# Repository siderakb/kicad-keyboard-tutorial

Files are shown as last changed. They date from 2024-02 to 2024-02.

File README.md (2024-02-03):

# KiCad Keyboard Tutorial

KiCAD 教學示範用的 60% 機械鍵盤。

[線上預覽](https://kicanvas.org/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)，由 [KiCanvas](https://github.com/theacodes/kicanvas) 提供。

- YouTube: [自製QMK鍵盤-KiCAD鍵盤PCB繪製教學  (上)](https://youtu.be/DOluUYmqIs4)
- Blog: [[自製QMK鍵盤-4] KiCAD鍵盤PCB繪製教學  (上)](https://ziteh.github.io/posts/diyqmkkeyboard-pcb-layout-sch/)

## 用法

從 Code 按鈕或 [Releases](https://github.com/siderakb/kicad-keyboard-tutorial/releases) 頁面下載專案，或使用 Git 指令：
```
git clone --recurse-submodules https://github.com/siderakb/kicad-keyboard-tutorial.git
```

需要另外安裝 Footprint 庫：[ebastler/marbastlib](https://github.com/ebastler/marbastlib)。

本專案使用的 KiCad 版本爲 `Ver 7.0.8`。

## 授權許可

- [`my-keyboard`](./my-keyboard/) 資料夾：根據 [CERN-OHL-P v2](./LICENSE) 授權。
- [`key-switches.pretty`](https://github.com/siderakb/key-switches.pretty) 資料夾：根據該庫自身的授權許可進行授權。

請注意，根據授權許可，不提供任何形式的保固或保證。

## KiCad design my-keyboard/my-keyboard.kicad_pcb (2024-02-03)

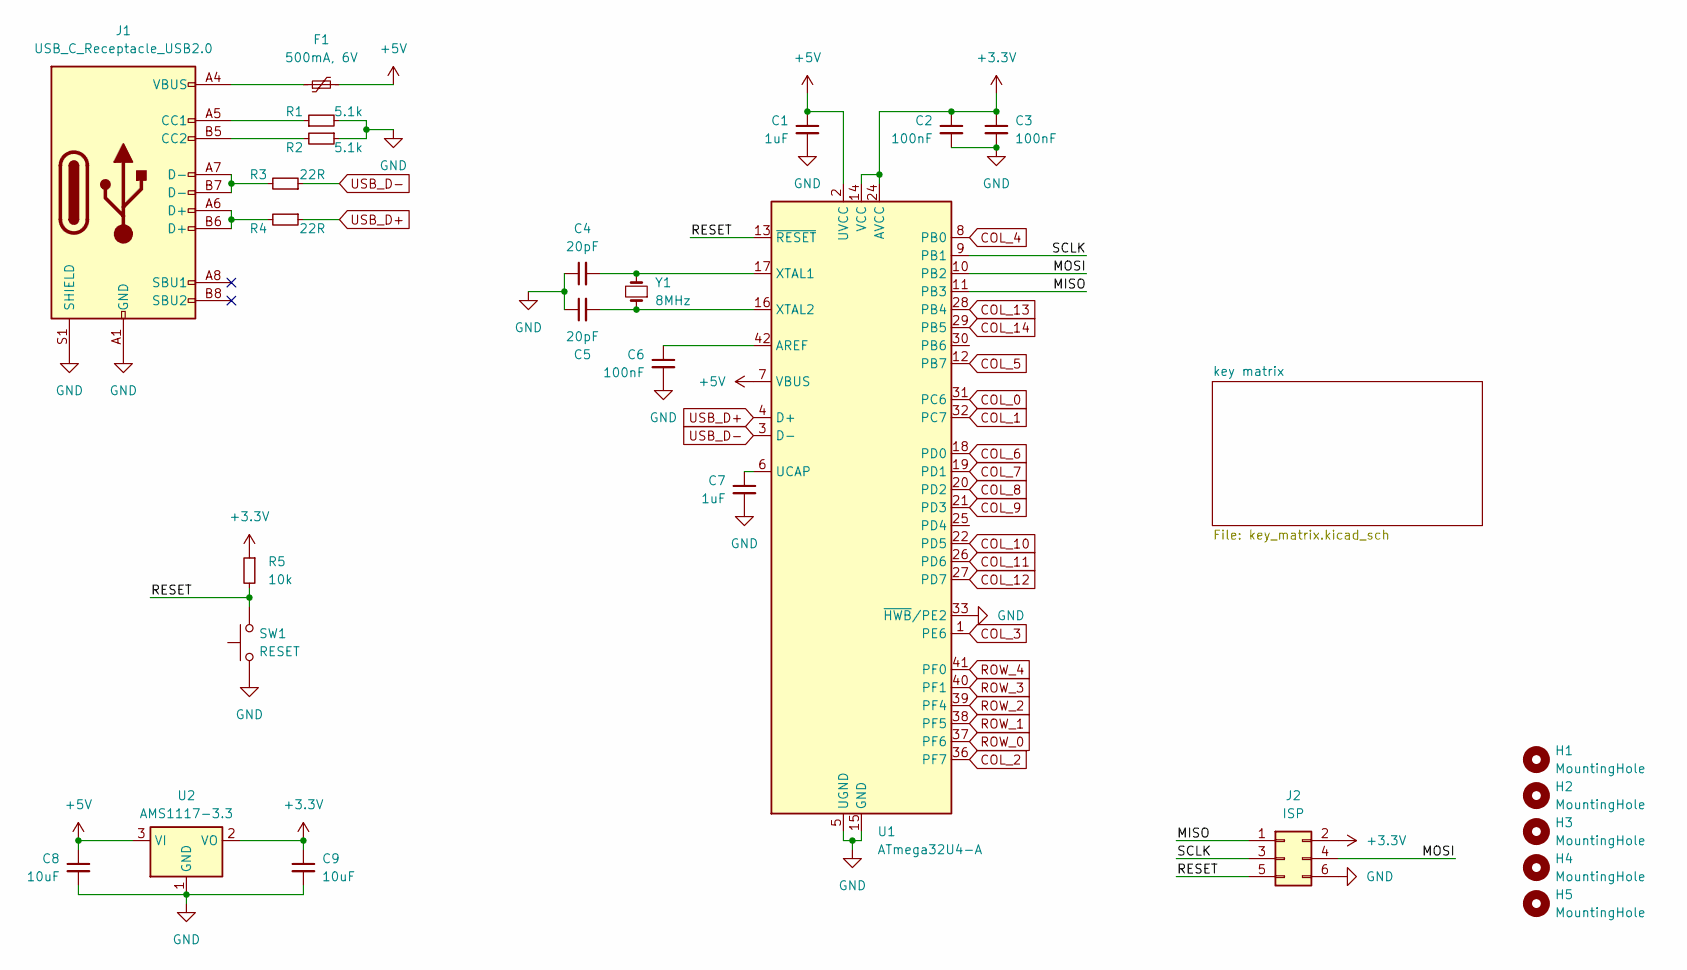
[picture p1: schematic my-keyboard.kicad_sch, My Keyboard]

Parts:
C1, C7: 1uF; C_0603_1608Metric
C2, C3, C6: 100nF; C_0603_1608Metric
C4, C5: 20pF; C_0603_1608Metric
C8, C9: 10uF; C_0603_1608Metric
F1: 500mA, 6V; Fuse_0805_2012Metric
H1, H2, H3, H4, H5: MountingHole; MountingHole_3.2mm_M3
J1: USB_C_Receptacle_USB2.0; USB_C_Receptacle_HRO_TYPE-C-31-M-12
J2: ISP; PinHeader_2x03_P2.54mm_Vertical
R1, R2: 5.1k; R_0603_1608Metric
R3, R4: 22R; R_0603_1608Metric
R5: 10k; R_0603_1608Metric
SW1: RESET; SW_SPST_CK_RS282G05A3
U1: ATmega32U4-A; TQFP-44_10x10mm_P0.8mm
U2: AMS1117-3.3; SOT-223-3_TabPin2
Y1: 8MHz; Crystal_SMD_3215-2Pin_3.2x1.5mm

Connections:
+3.3V: C2.1, C3.1, C9.1, J2.2, R5.1, U1.14 (VCC), U1.24 (AVCC), U1.34 (VCC), U1.44 (AVCC), U2.2 (VO)
+5V: C1.1, C8.1, F1.2, U1.2 (UVCC), U1.7 (VBUS), U2.3 (VI)
/MISO: J2.1, U1.11 (PB3)
/MOSI: J2.4, U1.10 (PB2)
/RESET: J2.5, R5.2, SW1.2, U1.13 (~RESET)
/SCLK: J2.3, U1.9 (PB1)
COL_0: U1.31 (PC6); also elsewhere on the board
COL_1: U1.32 (PC7); also elsewhere on the board
COL_2: U1.36 (PF7); also elsewhere on the board
COL_3: U1.1 (PE6); also elsewhere on the board
COL_4: U1.8 (PB0); also elsewhere on the board
COL_5: U1.12 (PB7); also elsewhere on the board
COL_6: U1.18 (PD0); also elsewhere on the board
COL_7: U1.19 (PD1); also elsewhere on the board
COL_8: U1.20 (PD2); also elsewhere on the board
COL_9: U1.21 (PD3); also elsewhere on the board
COL_10: U1.22 (PD5); also elsewhere on the board
COL_11: U1.26 (PD6); also elsewhere on the board
COL_12: U1.27 (PD7); also elsewhere on the board
COL_13: U1.28 (PB4); also elsewhere on the board
COL_14: U1.29 (PB5); also elsewhere on the board
GND: C1.2, C2.2, C3.2, C4.1, C5.1, C6.2, C7.2, C8.2, C9.2, J1.A1 (GND), J1.A12 (GND), J1.B1 (GND), J1.B12 (GND), J1.S1 (SHIELD), J2.6, R1.2, R2.1, SW1.1, U1.5 (UGND), U1.15 (GND), U1.23 (GND), U1.33 (~HWB/PE2), U1.35 (GND), U1.43 (GND), U2.1 (GND)
unnamed: F1.1, J1.A4 (VBUS), J1.A9 (VBUS), J1.B4 (VBUS), J1.B9 (VBUS)
unnamed: J1.A5 (CC1), R1.1
unnamed: J1.B5 (CC2), R2.2
unnamed: J1.A6 (D+), J1.B6 (D+), R4.2
unnamed: J1.A7 (D-), J1.B7 (D-), R3.2
unnamed: C6.1, U1.42 (AREF)
unnamed: C7.1, U1.6 (UCAP)
unnamed: C4.2, U1.17 (XTAL1), Y1.2
unnamed: C5.2, U1.16 (XTAL2), Y1.1
ROW_0: U1.37 (PF6); also elsewhere on the board
ROW_1: U1.38 (PF5); also elsewhere on the board
ROW_2: U1.39 (PF4); also elsewhere on the board
ROW_3: U1.40 (PF1); also elsewhere on the board
ROW_4: U1.41 (PF0); also elsewhere on the board
USB_D+: R4.1, U1.4 (D+)
USB_D-: R3.1, U1.3 (D-)

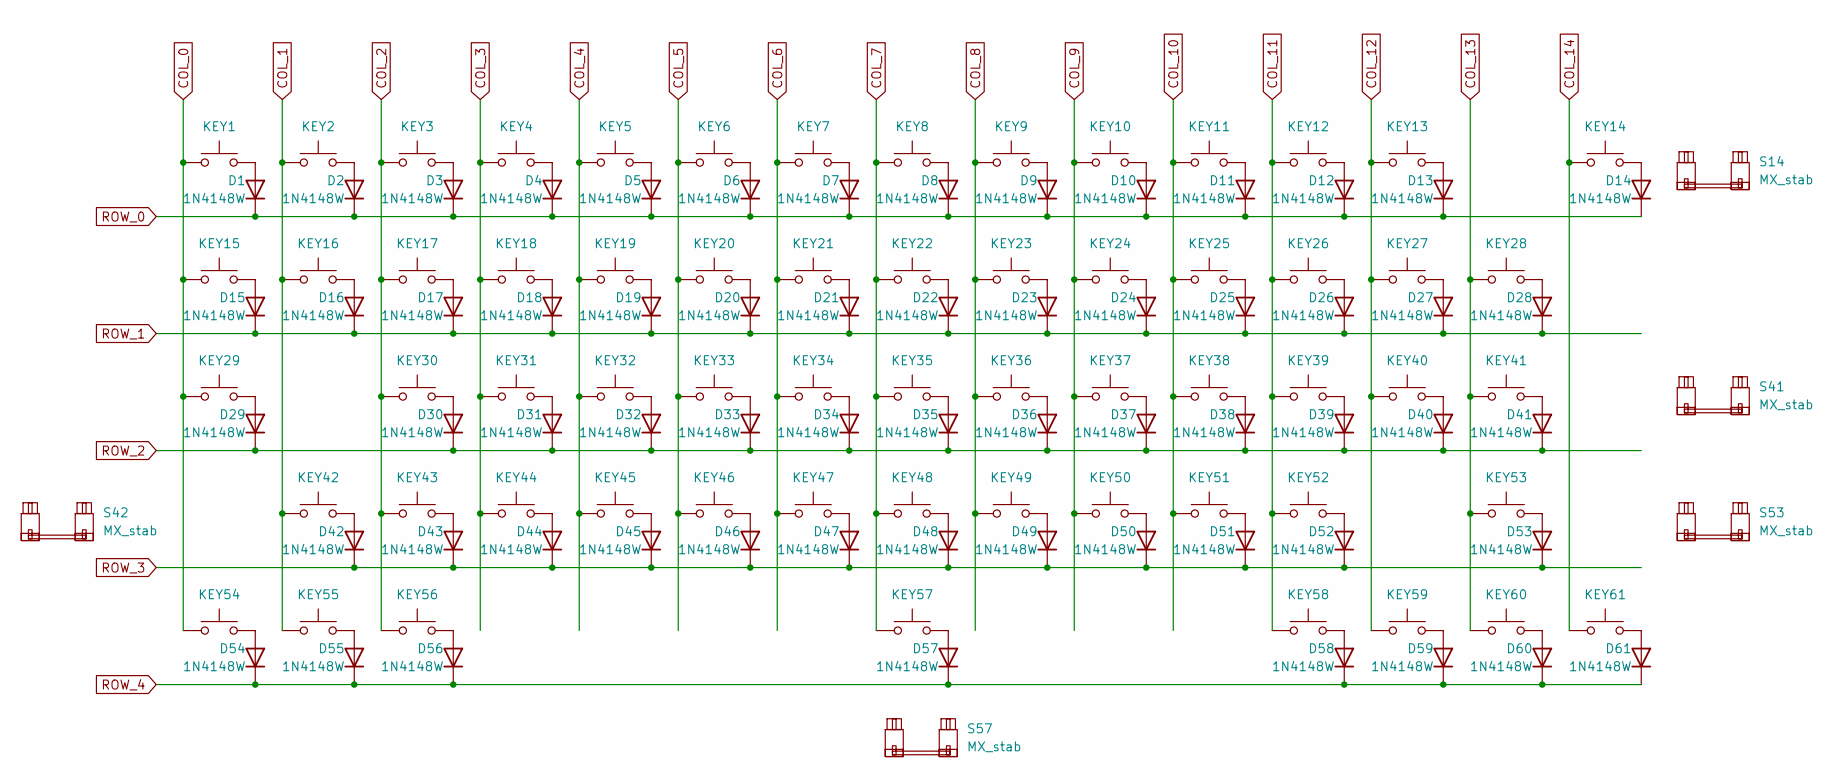
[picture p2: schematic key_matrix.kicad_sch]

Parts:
D1, D2, D3, D4, D5, D6, D7, D8, D9, D10, D11, D12, D13, D14, D15, D16, D17, D18, D19, D20, D21, D22, D23, D24, D25, D26, D27, D28, D29, D30, D31, D32, D33, D34, D35, D36, D37, D38, D39, D40, D41, D42, D43, D44, D45, D46, D47, D48, D49, D50, D51, D52, D53, D54, D55, D56, D57, D58, D59, D60, D61: 1N4148W; D_SOD-123
KEY1, KEY2, KEY3, KEY4, KEY5, KEY6, KEY7, KEY8, KEY9, KEY10, KEY11, KEY12, KEY13, KEY14, KEY15, KEY16, KEY17, KEY18, KEY19, KEY20, KEY21, KEY22, KEY23, KEY24, KEY25, KEY26, KEY27, KEY28, KEY29, KEY30, KEY31, KEY32, KEY33, KEY34, KEY35, KEY36, KEY37, KEY38, KEY39, KEY40, KEY41, KEY42, KEY43, KEY44, KEY45, KEY46, KEY47, KEY48, KEY49, KEY50, KEY51, KEY52, KEY53, KEY54, KEY55, KEY56, KEY57, KEY58, KEY59, KEY60, KEY61: SW_Push; SW_MX_HotSwap_PTH
S14: MX_stab; STAB_MX_P_2u
S41, S42: MX_stab; STAB_MX_P_2.25u
S53: MX_stab; STAB_MX_P_2.75u
S57: MX_stab; STAB_MX_P_6.25u

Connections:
COL_0: KEY1.1, KEY15.1, KEY29.1, KEY54.1; also elsewhere on the board
COL_1: KEY2.1, KEY16.1, KEY42.1, KEY55.1; also elsewhere on the board
COL_2: KEY3.1, KEY17.1, KEY30.1, KEY43.1, KEY56.1; also elsewhere on the board
COL_3: KEY4.1, KEY18.1, KEY31.1, KEY44.1; also elsewhere on the board
COL_4: KEY5.1, KEY19.1, KEY32.1, KEY45.1; also elsewhere on the board
COL_5: KEY6.1, KEY20.1, KEY33.1, KEY46.1; also elsewhere on the board
COL_6: KEY7.1, KEY21.1, KEY34.1, KEY47.1; also elsewhere on the board
COL_7: KEY8.1, KEY22.1, KEY35.1, KEY48.1, KEY57.1; also elsewhere on the board
COL_8: KEY9.1, KEY23.1, KEY36.1, KEY49.1; also elsewhere on the board
COL_9: KEY10.1, KEY24.1, KEY37.1, KEY50.1; also elsewhere on the board
COL_10: KEY11.1, KEY25.1, KEY38.1, KEY51.1; also elsewhere on the board
COL_11: KEY12.1, KEY26.1, KEY39.1, KEY52.1, KEY58.1; also elsewhere on the board
COL_12: KEY13.1, KEY27.1, KEY40.1, KEY59.1; also elsewhere on the board
COL_13: KEY28.1, KEY41.1, KEY53.1, KEY60.1; also elsewhere on the board
COL_14: KEY14.1, KEY61.1; also elsewhere on the board
unnamed: D1.2 (A), KEY1.2
unnamed: D2.2 (A), KEY2.2
unnamed: D3.2 (A), KEY3.2
unnamed: D4.2 (A), KEY4.2
unnamed: D5.2 (A), KEY5.2
unnamed: D6.2 (A), KEY6.2
unnamed: D7.2 (A), KEY7.2
unnamed: D8.2 (A), KEY8.2
unnamed: D9.2 (A), KEY9.2
unnamed: D10.2 (A), KEY10.2
unnamed: D11.2 (A), KEY11.2
unnamed: D12.2 (A), KEY12.2
unnamed: D13.2 (A), KEY13.2
unnamed: D14.2 (A), KEY14.2
unnamed: D15.2 (A), KEY15.2
unnamed: D16.2 (A), KEY16.2
unnamed: D17.2 (A), KEY17.2
unnamed: D18.2 (A), KEY18.2
unnamed: D19.2 (A), KEY19.2
unnamed: D20.2 (A), KEY20.2
unnamed: D21.2 (A), KEY21.2
unnamed: D22.2 (A), KEY22.2
unnamed: D23.2 (A), KEY23.2
unnamed: D24.2 (A), KEY24.2
unnamed: D25.2 (A), KEY25.2
unnamed: D26.2 (A), KEY26.2
unnamed: D27.2 (A), KEY27.2
unnamed: D28.2 (A), KEY28.2
unnamed: D29.2 (A), KEY29.2
unnamed: D30.2 (A), KEY30.2
unnamed: D31.2 (A), KEY31.2
unnamed: D32.2 (A), KEY32.2
unnamed: D33.2 (A), KEY33.2
unnamed: D34.2 (A), KEY34.2
unnamed: D35.2 (A), KEY35.2
unnamed: D36.2 (A), KEY36.2
unnamed: D37.2 (A), KEY37.2
unnamed: D38.2 (A), KEY38.2
unnamed: D39.2 (A), KEY39.2
unnamed: D40.2 (A), KEY40.2
unnamed: D41.2 (A), KEY41.2
unnamed: D42.2 (A), KEY42.2
unnamed: D43.2 (A), KEY43.2
unnamed: D44.2 (A), KEY44.2
unnamed: D45.2 (A), KEY45.2
unnamed: D46.2 (A), KEY46.2
unnamed: D47.2 (A), KEY47.2
unnamed: D48.2 (A), KEY48.2
unnamed: D49.2 (A), KEY49.2
unnamed: D50.2 (A), KEY50.2
unnamed: D51.2 (A), KEY51.2
unnamed: D52.2 (A), KEY52.2
unnamed: D53.2 (A), KEY53.2
unnamed: D54.2 (A), KEY54.2
unnamed: D55.2 (A), KEY55.2
unnamed: D56.2 (A), KEY56.2
unnamed: D57.2 (A), KEY57.2
unnamed: D58.2 (A), KEY58.2
unnamed: D59.2 (A), KEY59.2
unnamed: D60.2 (A), KEY60.2
unnamed: D61.2 (A), KEY61.2
ROW_0: D1.1 (K), D2.1 (K), D3.1 (K), D4.1 (K), D5.1 (K), D6.1 (K), D7.1 (K), D8.1 (K), D9.1 (K), D10.1 (K), D11.1 (K), D12.1 (K), D13.1 (K), D14.1 (K); also elsewhere on the board
ROW_1: D15.1 (K), D16.1 (K), D17.1 (K), D18.1 (K), D19.1 (K), D20.1 (K), D21.1 (K), D22.1 (K), D23.1 (K), D24.1 (K), D25.1 (K), D26.1 (K), D27.1 (K), D28.1 (K); also elsewhere on the board
ROW_2: D29.1 (K), D30.1 (K), D31.1 (K), D32.1 (K), D33.1 (K), D34.1 (K), D35.1 (K), D36.1 (K), D37.1 (K), D38.1 (K), D39.1 (K), D40.1 (K), D41.1 (K); also elsewhere on the board
ROW_3: D42.1 (K), D43.1 (K), D44.1 (K), D45.1 (K), D46.1 (K), D47.1 (K), D48.1 (K), D49.1 (K), D50.1 (K), D51.1 (K), D52.1 (K), D53.1 (K); also elsewhere on the board
ROW_4: D54.1 (K), D55.1 (K), D56.1 (K), D57.1 (K), D58.1 (K), D59.1 (K), D60.1 (K), D61.1 (K); also elsewhere on the board

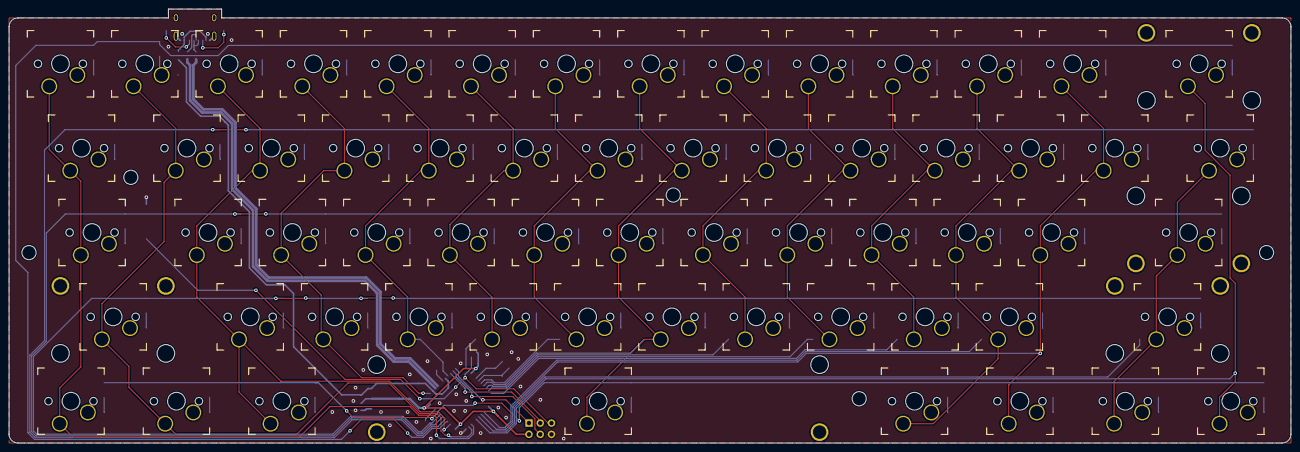
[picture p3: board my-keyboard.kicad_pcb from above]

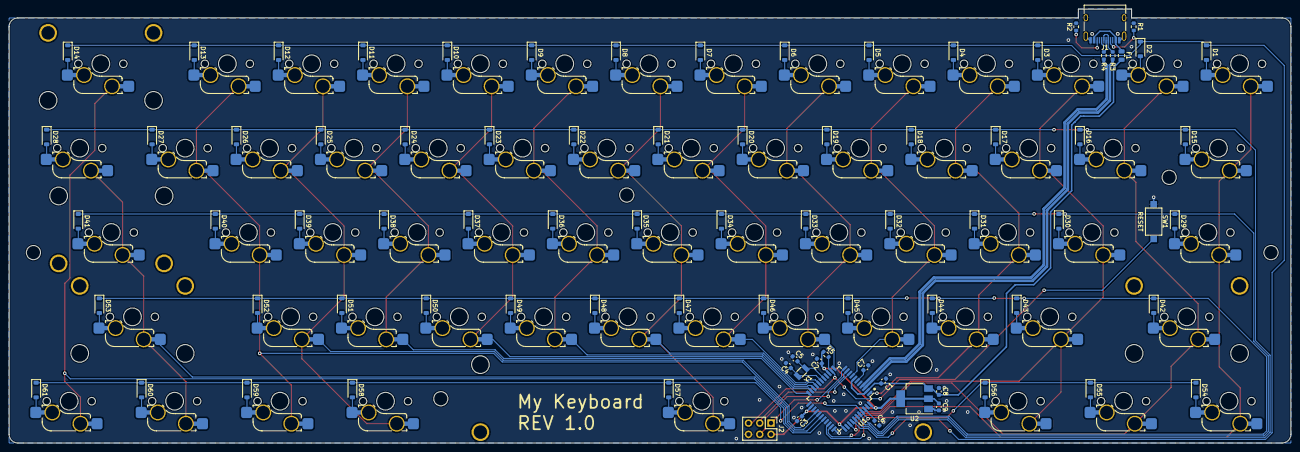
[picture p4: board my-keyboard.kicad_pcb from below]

Board: 2 copper layers, 289.5 x 98.0 mm, 153 parts (87 on the bottom side), 99 nets.

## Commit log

2023-11-12 Add KiCad files
    [key_matrix.kicad_sch, my-keyboard.kicad_pcb, my-keyboard.kicad_sch]
2024-02-03 Update PCB layout
    [my-keyboard.kicad_pcb, my-keyboard.kicad_sch]
